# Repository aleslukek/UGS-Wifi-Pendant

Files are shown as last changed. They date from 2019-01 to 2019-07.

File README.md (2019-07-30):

# UGS-Wifi-Pendant
This is an addon for an [Universal Gcode Sender](https://github.com/winder/Universal-G-Code-Sender). It enables a bit more complicated control of your CNC as well as LCD output of useful info.

It supports Old and New pendant. Communication is done via Wifi OR USB Serial. However, if you'd want for communication to work via USB cable (more reliable) you will have to have PowerShell script running in the background. This script listens to Serial on COM port (COMX should be replaced with the COM port of the Pendant device connected to the computer) and converts them to web and get requests via localhost to UGS Pendant. So it is quick, reliable but it is a bodge work. Not elegant but it works. I do not speak java good enough to implement this into UGS. I built this feature upon already working Wifi solution.

## What it does?
It takes buttons input and translates it to web requests that commands UGS via it's wifi pendant. You can move CNC (x, y z), slow move, start home cycle, z probe, reset XYZ zero, reset Z zero, return to XY zero, return to Z zero, pause, start job, cancel, toggle laser mode, soft reset, toggle source computer, auto connect GRBL Arduino to UGS, etc.

When the job is done it can send a notification via IFTTT.com.

OTA updates via local network (tested via Arduino IDE)!

It uses LCD to output CNC data, such as machine position, work position, job duration, job time remaining, job sent rows, total rows, progress, errors and things like that.

When job is running most of the buttons are disabled. Only pause, cancel and toggles are working. So you can't accidentally send commands that have nothing to do with job running.

## What buttons do?

* Button 0 - Homing / Z Probe
* Button 1 - Reset XYZ Zero / Reset Z zero
* Button 2 - Shift, if slow toggle is 1, and laser mode is 1 shift turns on laser test
* Button 3 - Pause-Resume / Laser mode (toggle laser mode if enableLaserMode is enabled) OR toggle Check mode
* Button 4 - Cancel (or $X on idle) / Soft reset + $X
* Button 5 - Y- / Return to XY zero
* Button 6 - Y+ / Return to XY zero
* Button 7 - X- / Return to XY zero
* Button 8 - X+ / Return to XY zero
* Button 9 - Z- / Return to Z zero
* Button 10 - Z+ / Return to Z zero
* Button 11 - Slow/fast toggle for jogging
* Button 12 - N/A
* Button 13 - N/A
* Button 14 - N/A
* Button 15 - PC1, PC2 toggle

--

* Buttons 5 - 10: jogging buttons. They work in two ways: press and hold a button will start jogging. When you release a button it will stop the movement. Second way is a quick press on a button it will start moving until the full step size is reached or until you press cancel or any jog button again.
* Button 2 acts as shift. Example: If you press button 0 CNC starts homing cycle. If you press button 2 (shift) + button 0 then it starts probing.  
* Button 3 start job if file selected when CNC is idle and pauses job when CNC is running.
* Button 2 + Button 3 (shift + pause) toggles laser mode $32=1 and $32=0. This pendant is unaware of current CNC laser mode. So if you press those two buttons even if laser mode is on it will turn it on not off. And vice versa. When laser mode is on led 1 is on.
* Button 4 cancels running job or jog, but acts as $X when idle. Shift + Button 4 soft resets the GRBL device.
Button 11 is as toggle. When not pressed CNC jogs with higher feed rate. When toggle is pressed, led 2 turns on and jogging is slower.
* Button 2 + any X/Y button returns to XY work zero (G90 G0 X0 Y0). This action observes slow/quick toggle and acts accordingly.
* Button 2 + any Z button returns to Z work zero (G90 G0 Z0). This action observes slow/quick toggle and acts accordingly.
* When laser mode is on ($32=1) and slow toggle is also on (so both LEDs are on) button 2 acts as laser test fire. It fires laser at slowest power. Be aware that if you have spindle connected to Spindle enable pin on grbl Arduino it will turn on your spindle. That might be much more dangerous than laser on lowest power. But lasers are dangerous as well, don't get me wrong. USE AT YOUR OWN RISK!

## What it needs?

  * ESP8266
  * At least two shift in registers 74HC165N
  * LM324N Op amp -> this could help with signalling 0V when button not pressed and +V when button pressed
  * I2C LCD 16*2
  * Buttons - momentary 5x
  * Moaar buttons - rocker switch on-off-on 3x
  * Toggle buttons/switches 2x
  * Trimmer 100k or 10k
  * Screw terminal
  * 22uF capacitors 16x
  * 1000k resistors 16x
  * 2 LEDs

* Be mindful that button must be connected in such a way that signals 0V when not pressed and +V (3.3V) when pressed. If you only send +V when button is pressed and not 0V when not pressed it will trigger shift registers.

## IFTTT notification

To enable IFTTT notification you must find your IFTTT Key found [somewhere here](https://ifttt.com/maker_webhooks) and assign it to "iftttKey" variable. Also at this point you must make an event (trigger) with event name. IFTTT event name must match to a variable "iftttEventName" found in UGS_Wifi_Pendant.ino. I would recommend IFTTT notification action to be: "CNC event on {{OccurredAt}}. Message: {{Value1}}". Value1 is an event message.

IFTTT notification happens when job is aborted by an error (hard limit or general error) or when CNC goes to sleep mode after a job - if a gcode file has $SLP at the end.
Canceling and pausing a job wont trigger a notification (since you are probably standing next to it). Also if a job does not have a $SLP at the end of a gcode file this will not send a notification. You should always use $SLP when doing a job when you are not around.

## How to compile...

Obviously you'll need Arduino IDE or something that sends code to your ESP8266.
Then you'll have to set some things up, really simply. You don't need to change any other code other than the one in UGS_Wifi_Pendant.ino

* Pendant version. Uncomment the version you have. If you still use old UGS Wifi Pendant then uncomment OLD_PENDANT. If you use New Pendant and via Wifi use NEW_BREILERS_PENDANT. If you use New Pendant and via USB use BUTTONSTOSERIAL. ONLY ONE SHOULD BE UNCOMMENTED! BUTTONSTOSERIAL only works with new pendant.
        //#define OLD_PENDANT
        //#define NEW_BREILERS_PENDANT
        //#define BUTTONSTOSERIAL

* Wifi settings, self-explanatory. Just enter ssid and wifi password.

* If you have CNC dedicated pc (or Raspberry pi) but also use laptop occasionally to control CNC you can use toggle to switch between them. I highly recommend to set static network ip for those devices on your local router. Name pc 1 and give it local ip. Also for pc 2. Or a mac or anything else that runs UGS. Server port is set to default to 8080 for both devices. I don't see a need for different ports on different devices. So it's the same one for both of them. Port name is so the UGS Pendant can auto-connect GRBL Device to UGS.

        controler1Name "PC1" //PC 1 name
        webserver1 "xxx.xxx.xxx.xxx" //PC 1 local ip
        port1 "COMX" //PC 1 GRBL arduino port name

        controler2Name "PC2" //PC 2 name
        webserver2 "xxx.xxx.xxx.xxx" //PC 2 local ip
        port2 "COMX" //PC 2 GRBL arduino port name

        webserverport = "8080";

        iftttKey - your IFTTT Webhook key
        iftttEventName - ifttt event name. MUST match the one on IFTTT website.

#### Personal settings that make anything working better.
         xyStepSizeFast 800  - x and y step size for quick jog. Might be as long as you want.
         xyStepRateFast 5000 - x and y feed rate for quick jog
         xyStepSizeSlow 200 - x and y step size for slow jog
         xyStepRateSlow 500 - x and y feed rate for slow jog
         probeStep 20 - probing Z axis step size
         probeRate 50 - probing Z axis feed rate
         drillProbeHeight 2 - height of a probe. When it reaches a probe it will offset Z axis for this amount of mm
         enableLaserMode true - if you also use laser keep this enabled. If not it won't use any of those laser features
         laserProbeHeight 0 - probing Z axis probe offset. Same function as drillProbeHeight but different offset if you need
         skipGetDelay 50 - when button is pressed, no other button will register after skipGetDelay milliseconds
         skipMsgDelay 1000 - when button is pressed, display what happened and after skipMsgDelay milliseconds display regular status
         turnBacklightDelay 600000 - turn off LCD backlight after this many milliseconds of inactivity
         jumpSign 5000 - jump sign after 5000 ms (cycling data when idle or running)
         autoResetAlarm false - if you want for pendant to automatically send $X when idle and alarm was triggered (not Hard Limit alarm) set true, else it will not
         autoResetStartupAlarm true - automatically send $X on startup to remove general alarm
         enableSerialOutput true - Enables serial output. For debugging purposes. Disable if not needed. Will make code run a small bit faster.
         enableIftttMessaging true - Enables IFTTT notifications.

         enableOTAUpdate true - enables Over The Air (over local wifi) firmware updates.
         enableOTAPassword true - enables the need for password when OTA updating.
         OTAPassword "******" - if enableOTAUpdate is enabled, enter a password you will have to enter when OTA updating next time. This password is printed on fresh boot via serial.

#### Personal settings for serialToUGS.ps1 file.
        Basically you will only need to figure out what COM port UGS pendant uses. So rename COMX in $PORT='COMX' to whatever COM port it is used. COM5 in my case. If you change USB Port you should change this as well.
        Make sure it works in the background. You can use Windows Task Scheduler to make it start on boot as described [here](https://blog.netwrix.com/2018/07/03/how-to-automate-powershell-scripts-with-task-scheduler/).

* LCD language. Uncomment the wanted one and comment the unwanted one. Currently English and Slovenian. If you'd like to contribute or change, language is in file e_lcd_lang.ino
#define LanguageEnglish
//#define LanguageSlovenian

* Extra, non standard libraries are included in the sketch in src folder. Leave them there, since libraries are pointed there.

* This code checks for buttons state and button logic more than 1000 times per second. When state of any button changes it sends a request. It is done fairly quickly and I haven't encountered any lags or delays. LCD is updated almost every half a second or so. So everything works quite tightly.

# Connections
 * 3V - LCD VCC
 * GND - LCD GND
 * D1 - LCD SCL
 * D2 - LCD SDA
 * D3 - led for laser mode status (on if laser mode is on)
 * D5 - led for speed mode status (on if slow)

Please refer to schematic in schematic folder for if you'd like to make a PCB for it. I made it, trust me, it is worth it. Soldering this is a path you don't want to go to. I used https://easyeda.com to design the schematic (you can easily import it in easyeda. I haven't tested other schematic apps) and pcb and https://jlcpcb.com/ to manufacture 10 pieces for 2 USD + shipping.

# Known issues
* Old UGS Pendant: Soft reset won't work until UGS starts to support soft reset via get request. New UGS Pendant has a soft reset so it works.
* Laser test fire doesn't fire consistently. When it does it might freeze grbl. But sometimes it does not. Not because get requests are not getting through but for some (so far to me) unknown reason, I assume connected to grbl.
* Very rarely jogging stops responding. It start moving and then it doesn't stop. Cancel button doesn't work, it jogs until it hits hard limit switch. For that reason I would strongly recommend to ONLY use this pendant on machines that have hard limits working in all directions. For safety reason of course. I haven't pinpointed the issue to either wifi pendant, ugs, grbl or esp pendant. - On new pendant and USB communication I haven't encountered this issue while testing. USB makes things MUCH MORE reliable so this things should not occur again. Requests via wifi might get delayed or lost in a transmition.

# WARNING
Before embarking on this project READ THIS README! And then again and again. Then think before you do anything that can endanger personal safety or cause damage. Make sure you understand how it works before start using it!

Use this UGS_Wifi_Pendant **ONLY** on machines that have hard limit switches in **ALL** directions! If things start moving and you for some reason don't or can't press stop button at least have limit switches that stop everything.

Read and understand what buttons and combination of buttons do! Failing to understand this might endanger your personal safety and might cause damage to your machine. And other things.

Wear your safety glasses and ear mufflers.

**AND ALWAYS KEEP YOUR HANDS AND OTHER EQUIPMENT OFF YOUR CNC WHEN USING IT!**

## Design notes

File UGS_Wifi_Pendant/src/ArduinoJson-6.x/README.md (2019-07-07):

ArduinoJson

---







ArduinoJson is a C++ JSON library for Arduino and IoT (Internet Of Things).

## Features

* JSON decoding (comments are supported)
* JSON encoding (with optional indentation)
* MessagePack
* Elegant API, easy to use
* Fixed memory allocation (zero malloc)
* No data duplication (zero copy)
* Portable (written in C++98, can be used in any C++ project)
* Self-contained (no external dependency)
* Small footprint
* Input and output streams
* [100% code coverage](https://coveralls.io/github/bblanchon/ArduinoJson)
* [Header-only library](https://en.wikipedia.org/wiki/Header-only)
* [MIT License](https://en.wikipedia.org/wiki/MIT_License)
* [Comprehensive documentation](https://arduinojson.org?utm_source=github&utm_medium=readme)

## Compatibility

ArduinoJson works on the following hardware:

*  Arduino boards: [Uno](https://www.arduino.cc/en/Main/ArduinoBoardUno), [Due](https://www.arduino.cc/en/Main/ArduinoBoardDue), [Mini](https://www.arduino.cc/en/Main/ArduinoBoardMini), [Micro](https://www.arduino.cc/en/Main/ArduinoBoardMicro), [Yun](https://www.arduino.cc/en/Main/ArduinoBoardYun)...
*  Espressif chips: [ESP8266](https://en.wikipedia.org/wiki/ESP8266), [ESP32](https://en.wikipedia.org/wiki/ESP32)
*  WeMos boards: [D1](https://wiki.wemos.cc/products:d1:d1), [D1 mini](https://wiki.wemos.cc/products:d1:d1_mini),  ...
*  RedBearLab boards: [BLE Nano](http://redbearlab.com/blenano/), [BLE Mini](http://redbearlab.com/blemini/), [WiFi Micro](https://redbear.cc/product/wifi/wifi-micro.html), [LOLIN32](https://wiki.wemos.cc/products:lolin32:lolin32)...
*  [Teensy](https://www.pjrc.com/teensy/) boards
*  Intel boards: Edison, Galileo...
*  Particle boards: [Photon](https://www.particle.io/products/hardware/photon-wifi-dev-kit), [Electron](https://www.particle.io/products/hardware/electron-cellular-dev-kit)...
*  Texas Instruments boards: [MSP430](http://www.ti.com/microcontrollers/msp430-ultra-low-power-mcus/overview/overview.html)...

ArduinoJson compiles with zero warning on the following compilers, IDEs, and platforms:

*  [Arduino IDE](https://www.arduino.cc/en/Main/Software)
*  [PlatformIO](http://platformio.org/)
*  [Energia](http://energia.nu/)
*  [Visual Micro](http://www.visualmicro.com/)
*  [Atmel Studio](http://www.atmel.com/microsite/atmel-studio/)
*  [IAR Embedded Workbench](https://www.iar.com/iar-embedded-workbench/)
*  [Atollic TrueSTUDIO](https://atollic.com/truestudio/)
*  [Keil uVision](http://www.keil.com/)
*  [MPLAB X IDE](http://www.microchip.com/mplab/mplab-x-ide)
*  [GCC](https://gcc.gnu.org/)
*  [Clang](https://clang.llvm.org/)
*  [Visual Studio](https://www.visualstudio.com/)

## Quickstart

### Deserialization

Here is a program that parses a JSON document with ArduinoJson.

```c++
char json[] = "{\"sensor\":\"gps\",\"time\":1351824120,\"data\":[48.756080,2.302038]}";

DynamicJsonDocument doc(1024);
deserializeJson(doc, json);

const char* sensor = doc["sensor"];
long time          = doc["time"];
double latitude    = doc["data"][0];
double longitude   = doc["data"][1];
```

See the [tutorial on arduinojson.org](https://arduinojson.org/doc/decoding/?utm_source=github&utm_medium=readme)

### Serialization

Here is a program that generates a JSON document with ArduinoJson:

```c++
DynamicJsonDocument doc(1024);

doc["sensor"] = "gps";
doc["time"]   = 1351824120;

JsonArray data = doc.createNestedArray("data");
data.add(48.756080);
data.add(2.302038);

serializeJson(doc, Serial);
// This prints:
// {"sensor":"gps","time":1351824120,"data":[48.756080,2.302038]}
```

See the [tutorial on arduinojson.org](https://arduinojson.org/doc/encoding/?utm_source=github&utm_medium=readme)

## Documentation

The documentation is available on [arduinojson.org](https://arduinojson.org/?utm_source=github&utm_medium=readme), here are some shortcuts:

* The [Examples](https://arduinojson.org/example/?utm_source=github&utm_medium=readme) show how to use the library in various situations.
* The [API Reference](https://arduinojson.org/api/?utm_source=github&utm_medium=readme) contains the description of each class and function.
* The [FAQ](https://arduinojson.org/faq/?utm_source=github&utm_medium=readme) has the answer to virtually every question.
* The [ArduinoJson Assistant](https://arduinojson.org/assistant/?utm_source=github&utm_medium=readme) writes programs for you!

---

Do you like this library? Please [star this project on GitHub](https://github.com/bblanchon/ArduinoJson/stargazers)!

What? You don't like it but you *love* it?
We don't take donations anymore, but [we sell a book](https://arduinojson.org/book/?utm_source=github&utm_medium=readme), so you can help and learn at the same time!

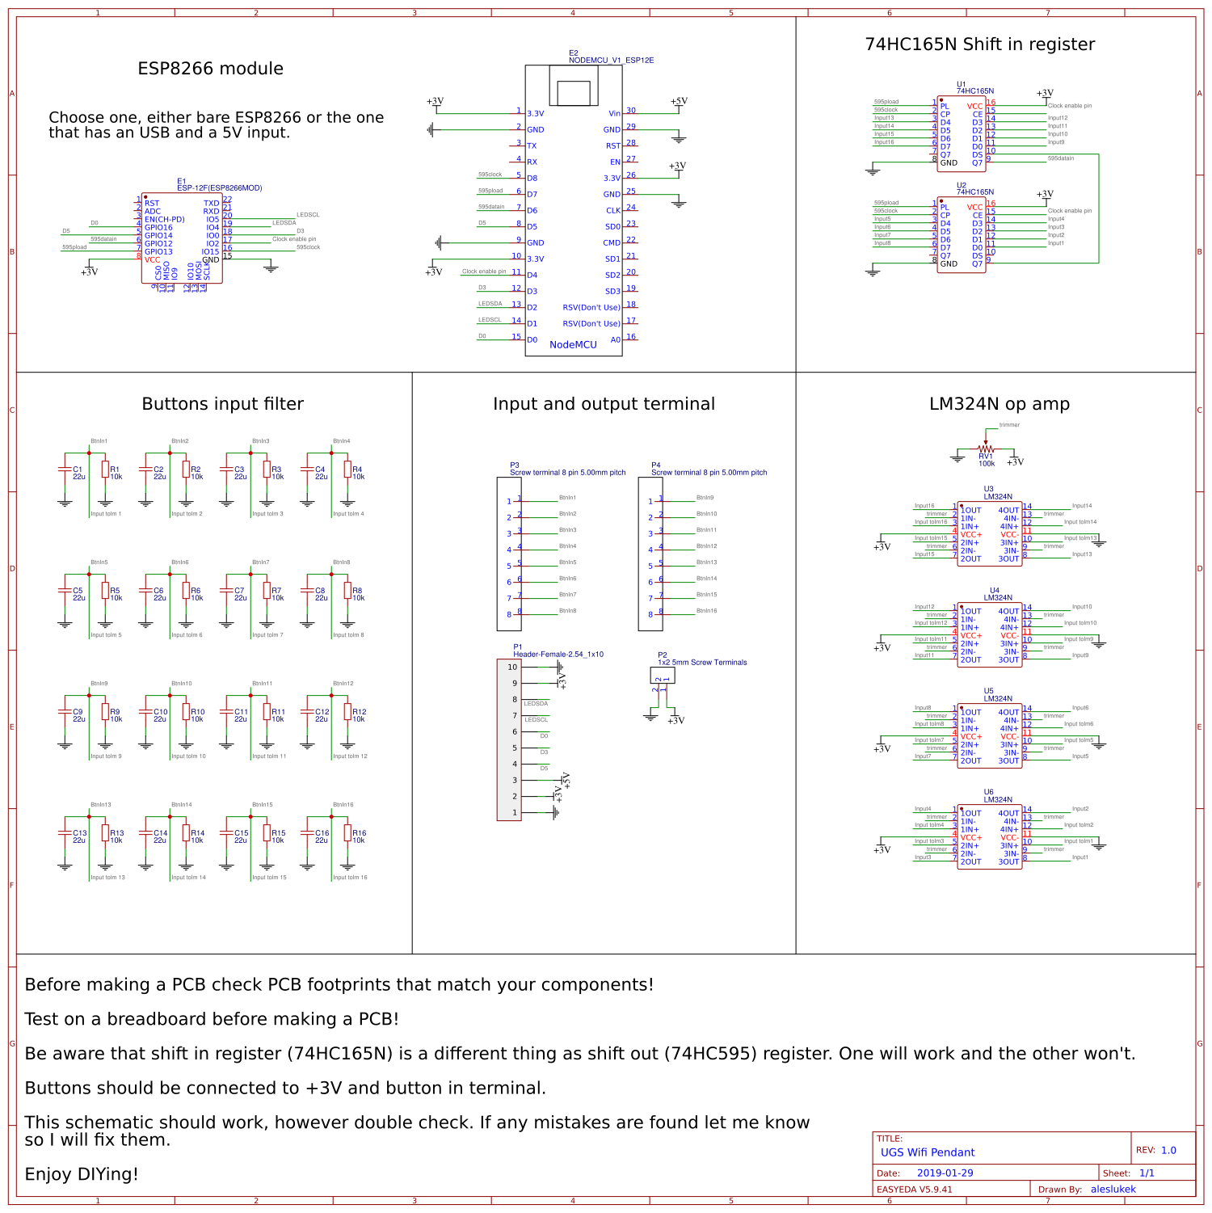
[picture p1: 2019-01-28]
Schematic/ugs wifi pendant.png

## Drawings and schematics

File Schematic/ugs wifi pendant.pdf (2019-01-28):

+3V | +5V

+3V

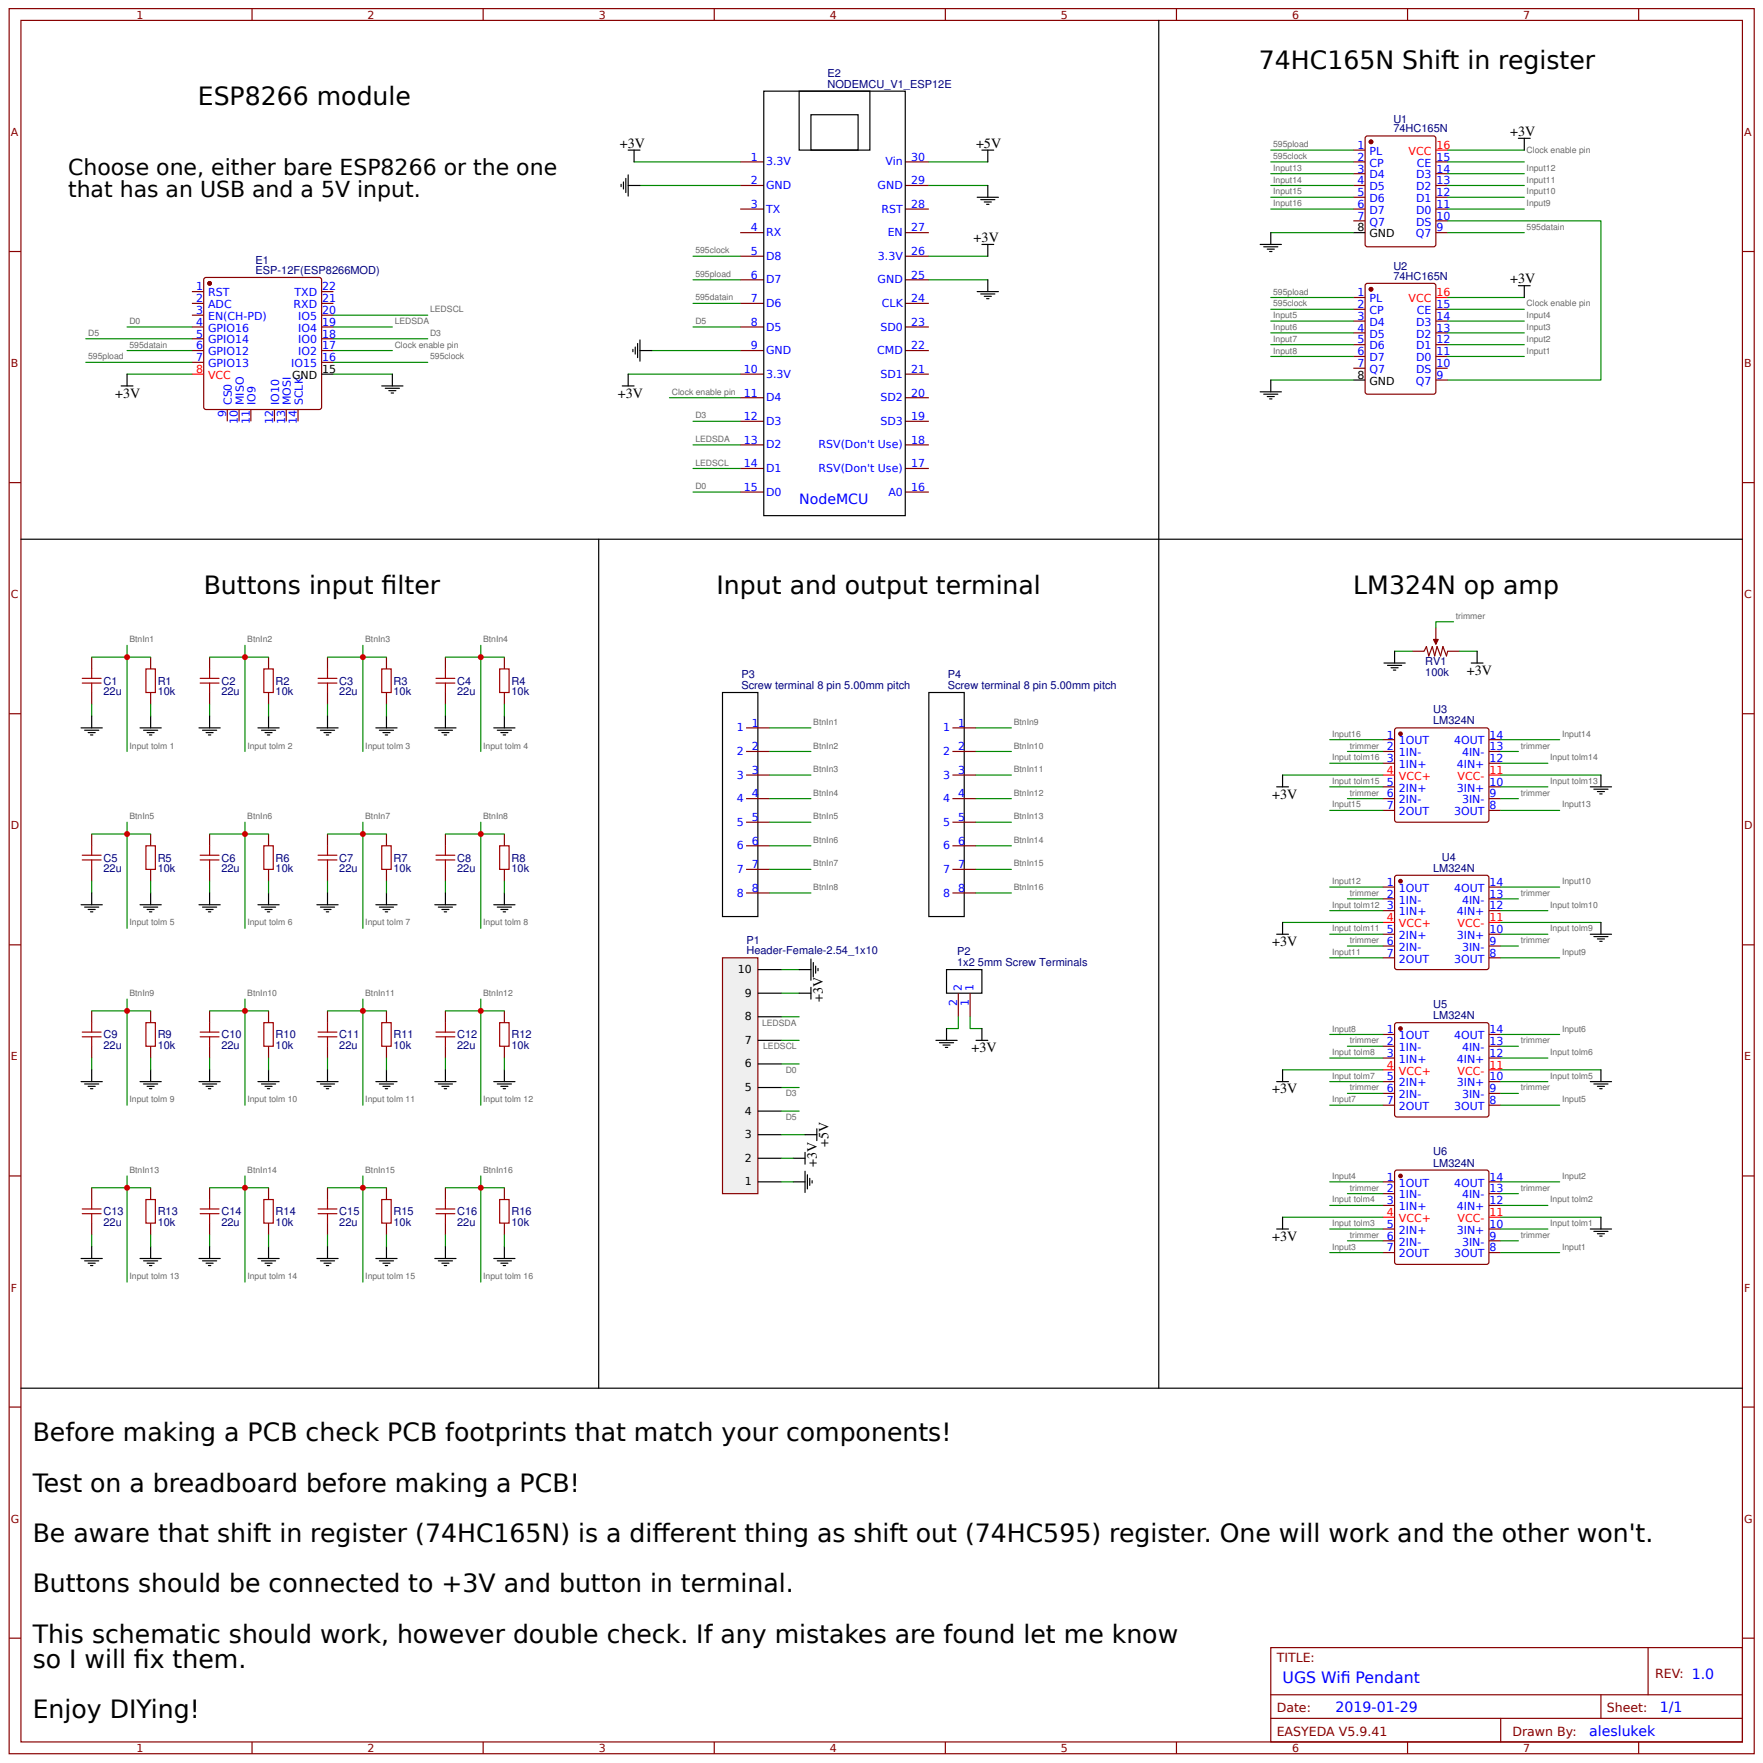
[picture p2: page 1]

Choose one, either bare ESP8266 or the one
that has an USB and a 5V input.

Screw terminal 8 pin 5.00mm pitch

Before making a PCB check PCB footprints that match your components!
Test on a breadboard before making a PCB!
Be aware that shift in register (74HC165N) is a different thing as shift out (74HC595) register. One will work and the other won't.
Buttons should be connected to +3V and button in terminal.
This schematic should work, however double check. If any mistakes are found let me know
so I will fix them.
Enjoy DIYing!

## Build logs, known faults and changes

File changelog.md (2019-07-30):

# 1.21 - 31.7.2019
* Small bug fixes.
* Removed chosen file name on LCD.
* Showing progress % was accidentally removed in previous build. Now it works.

# 1.20 - 8.7.2019
* This is a big one, guys! Added support for New Mr. Breiler's Pendant via Wifi.
* Also! Added support for New Pendant, BUT VIA USB! So This Wifi Pendant takes data via wifi, still has IFTTT messaging but commands are sent via USB cable. Since ESP cannot act as keyboard I managed a bodge - Powershell script (serialToUGS.ps1) that runs in a back that listens Wifi Pendant COM port and converts Serial Commands to localhost web requests. So Wifi Pendant should still run in a background. Since this are localhost requests commands are quicker, more reliable even if Pendant doesn't have the best wifi signal.
* Old pendant is as is, now Json Parsing is done by ArduinoJson 6 library. Better than my previous parser.
* Soft reset now works on new pendant.
* Some small bugs removed.
* Via this new pendant it is now possible that Wifi pendant automatically connects UGS to CNC. And cancels first Alarm.
* I couldn't be bothered but I assume that by using powershell you could remove the need for wifi (ESP) - so almost any Arduino could be used. I won't check since I have other things to do.

# 1.05 - 24.2.2019
* Added OTA updates. You can now update your module wirelessly. You can enable or disable OTA updates. You can also enable or disable OTA password.
* Changed how progress is being calculated. So it better handles empty rows and comments in gcode file.
* Changed how estimated remaining time is being calculated; it should not jump around like in UGS does. And it is more accurate. And it works by applying magic.

# 1.04 - 16.2.2019
* Added a notification system; it sends notifications to your phone via IFTTT.com when job is finished/aborted.
* Introduced small delay (20ms) to cancel command in cases when cancel command is requested right after jog command. This cancel command overrules 50 ms delay to all get requests.
* Some readme updates.
* Fixed speed issue when "return to zero" was not observing rate toggle (button 11).

# 1.03 - 13.2.2019
* Bugfix, added G91 to z probe. Sometimes Z probe was probing in wrong direction, depending on Z zero.

# 1.02 - 13.2.2019
* Some small code cleanup.

# 1.01 - 3.2.2019
* Added "return to zero" function. It splits XY return to zero and Z return to zero. Shift + direction buttons. Shift + X or Shift + Y to return to XY zero and Shift + Z to return to Z zero. It observes slow/quick toggle switch position for quick or slow return.

# 1.0
* Initial release.

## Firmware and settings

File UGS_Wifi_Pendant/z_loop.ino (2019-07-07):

//=======================================================================
//                    Main Program Loop
//=======================================================================
void loop() {
        read_shift_regs(); //read button state always, even if not connected
        buttonValues = read_shift_regs();
        //Serial.println(buttonValues);
        if(oldButtonValues != buttonValues) { //if any button was pressed, do your magic
                buttons();
                directionButtons();
                oldButtonValues = buttonValues;
                timer2 = millis(); //if any button was pressed reset backlight timer
                if(lcdBacklightStatus == 0) { //turn backlight on if it was turned off
                        lcd.backlight();
                        lcdBacklightStatus = 1;
                }
        }

        if((cnc_state[4] == 1 || cnc_state[7] == 1) && (directionStatus == 1 || directionStatusX == 1 || directionStatusY == 1 || directionStatusZ == 1) && (button[5] == 0 && button[6] == 0 && button[7] == 0 && button[8] == 0 && button[9] == 0 && button[10] == 0) ) { //re-check if button was de-pressed to stop the movement: when idle or jogging, buttons are not pressed, it should be moving
                directionStatusX = 0;
                directionStatusY = 0;
                directionStatusZ = 0;
                getCommandGeneral(GETcancel);
        }

        maintanance();
        if(cycleCounter % 1000 == 0) { //read UGS GET output every 1000 cycles
                timer4 = millis();
                //printSerialDebug(0);
                readUGSPendant();
                //printSerialDebug(1);
                if(cnc_state[0] == 1) { //if not connected to wifi, retry to connect
                        reConnectToWifi();
                }
                //printSerialDebug(3); //to time 1000 cycles and one get response read and parse
        }
        //printSerialDebug(3); //to time average of 100 cycles
}

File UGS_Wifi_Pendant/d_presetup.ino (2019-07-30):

#include <ESP8266WiFi.h>
#include <WiFiClient.h>
#include <ESP8266WebServer.h>
#include <ESP8266HTTPClient.h>
#include "src/ESP8266Ping/ESP8266Ping.h"
#include <ESP8266mDNS.h>
#include <WiFiUdp.h>
#include <ArduinoOTA.h>
#include "src/LiquidCrystal_I2C/LiquidCrystal_I2C.h"
#include "src/ArduinoJson-6.x/ArduinoJson.h"

#define  pendatVersion  1.21

LiquidCrystal_I2C lcd(0x3F, 16, 2);
#define resetPinD5 16 //D0

#define ledLaser 0 //D3 - led for laser mode status (on if lasermode is on)
#define ledSlow  14//D5 - led for speed mode status (on if slow)

bool justSentGeneral = 0;
bool justSentDirection = 0;
bool justSentMsgDisplay = 0;
bool ledLaserStatus = 0;
bool ledSlowStatus = 0;
int buttonPressMsg = 0; //what message to display when certain button is pressed
unsigned long timer1 = 0; //reset justSentGeneral to 0 after skipGetDelay ms
unsigned long timer2 = 0; //turn off backlight after turnBacklightDelay ms
unsigned long timer3 = 0; //calculate cycle duration
unsigned long timer4 = 0; //calculate cycle ugs get and parse duration
unsigned long timer5 = 0; //reset msg display after skipMsgDelay ms
unsigned int cycleCounter = 1;
unsigned int timerlcd = 0;
bool disableAlarmLockLogic = 1; //will send $X on startup if enabled. Also there to automatically send $X if alarm is set. Not for Hard Limit alarm
bool resetZAxisAfterProbe = 0;
bool turnOnLCD = 0;
bool lcdBacklightStatus = 0;
byte showLCD = 0;
bool laserMode = 0;
bool laserTest = 0;
bool connectCNCOnce = 0; //if 0 it connects CNC to computer automagically, if not then it will not connect CNC to computer
#define numOfStates 15
bool cnc_state[numOfStates] = {0, 0, 0, 0, 0, 0, 0, 0, 0, 0, 0, 0, 0, 0, 0};


/*

   CNC_State index:
   0 - esp wifi not connected
   1 - PC not available
   2 - PC available ugs or pendant not running
   3 - PC available, ugs available, arduino (cnc) connected to PC via serial
   4 - CNC is idle
   5 - CNC job is running
   6 - CNC job is on hold
   7 - CNC is jogging
   8 - Hard Limit Alarm triggered
   9 - General Alarm triggered
   10 - CNC is sleeping ($SLP triggered)
   11 - send btn enabled
   12 - pause btn enabled
   13 - cancel btn enabled
   14 - disable certain buttons while job is being done
 */

#define varLength 17
char textArray[500];
char variable[18][varLength];
String variableNames[17];

float workx, worky, workz, machinex, machiney, machinez;
float rowProgress;
int rowsInFile, sentRows, remainingRows, timeRemaining, duration;

bool button[16] = {0, 0, 0, 0, 0, 0, 0, 0, 0, 0, 0, 0, 0, 0, 0, 0};
bool prevButton[16] = {0, 0, 0, 0, 0, 0, 0, 0, 0, 0, 0, 0, 0, 0, 0, 0};
unsigned int buttonValues;
unsigned int oldButtonValues;

/*
   button[0] - top left button, Homing / Probe
   button[1] - top right button, Reset XYZ / Reset Z zero
   button[2] - middle button, Shift, if slow toggle is 1, and laser mode is 1 shift turns on laser test
   button[3] - bottom left button, Pause-Resume / Laser mode (toggle laser mode)
   button[4] - bottom right button, Cancel (or $X on idle) / Soft reset + $X
   button[5] - Y- / return to XY zero
   button[6] - Y+ / return to XY zero
   button[7] - X- / return to XY zero
   button[8] - X+ / return to XY zero
   button[9] - Z- / return to Z zero
   button[10] - Z+ / return to Z zero
   button[11] - slow/fast toggle for jogging
   button[12] - N/A
   button[13] - N/A
   button[14] - N/A
   button[15] - PC 1, PC 2 toggle
 */

// How many shift register chips are daisy-chained.
#define NUMBER_OF_SHIFT_CHIPS   2

// Width of data (how many ext lines).
#define DATA_WIDTH   NUMBER_OF_SHIFT_CHIPS * 8

// Width of pulse to trigger the shift register to read and latch.
#define PULSE_WIDTH_USEC   5

#define ploadPin        13 // Connects to Parallel load pin the 165
#define clockEnablePin  2 // Connects to Clock Enable pin the 165
#define dataPin         12 // Connects to the Q7 pin the 165
#define clockPin        15 // Connects to the Clock pin the 165

#ifdef OLD_PENDANT //old pendant commands
#define   GETmovexyz                "/sendGcode/?gCode=%24J%3DG21G91"
#define   GETresetzero              "/sendGcode/?gCode=G10%20P0%20L20%20X0%20Y0%20Z0"
#define   GETresetZzero             "/sendGcode/?gCode=G10%20P0%20L20%20Z"
#define   GETreturntozero           "/sendGcode/?gCode=RETURN_TO_ZERO"
#define   GETmoveToZeroZslowly      "/sendGcode/?gCode=G1%20G90%20Z0%20F50" //return to Z0 slowly
#define   GETmoveToZeroZquickly     "/sendGcode/?gCode=G1%20G90%20Z0%20F500" //return to X0 quickly
#define   GETmoveToZeroXYslowly     "/sendGcode/?gCode=G1%20G90%20X0%20Y0%20F500" //return to XY slowly
#define   GETmoveToZeroXYquickly    "/sendGcode/?gCode=G1%20G90%20X0%20Y0%20F5000" //return to XY quickly
#define   GETreturntoworkspace      "/sendGcode/?gCode=G0%20G90%20X0%20Y0%20Z0"
#define   GEThomingcycle            "/sendGcode/?gCode=%24H"
#define   GETdisablealarmlock       "/sendGcode/?gCode=%24X"
#define   GETtogglecheckmode        "/sendGcode/?gCode=%24C"
#define   GETsoftreset              "/sendGcode/?gCode=%24C" //run toggle check mode twice in a row
#define   GETspindleON              "/sendGcode/?gCode=M8"
#define   GETspindleOFF             "/sendGcode/?gCode=M9"
#define   GETpause                  "/sendGcode/?gCode=PAUSE_RESUME_FILE"
#define   GETsend                   "/sendGcode/?gCode=SEND_FILE"
#define   GETresume                 "/sendGcode/?gCode=PAUSE_RESUME_FILE"
#define   GETcancelJob              "/sendGcode/?gCode=CANCEL_FILE"
#define   GETcancel                 "/sendGcode/?gCode=CANCEL_FILE"
#define   GETsystemState            "/getSystemState/"
#define   GETtoggleLaser            "/sendGcode/?gCode=%2432%3D" //%36 should be $ Laser toggle is $32=
#define   GETlaserTestOn            "/sendGcode/?gCode=M3" //Run test as M04 Sxx (xx are laserTestStrength) - this will only turn on laser, but not fire it yet, since G1 command is not issued
#define   GETlaserTestPower         "/sendGcode/?gCode=M4%20S1" //Run test as M04 Sxx (xx are laserTestStrength) - this will only turn on laser, but not fire it yet, since G1 command is not issued
#define   GETlaserTestOff           "/sendGcode/?gCode=M5" //Turn off M4 with M05
#define   GETmoveLeftABit           "/sendGcode/?gCode=G1%20G91%20X-0.1%20F5000" //move relative 0.1 mm to left
#define   GETmoveRightABit          "/sendGcode/?gCode=G1%20G91%20X0.1%20F5000" //move relative 0.1 mm to right
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

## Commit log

2019-02-16 1.04
    IFTTT notifications, bug fixes
    [UGS_Wifi_Pendant.ino, d_presetup.ino, e_lcd_lang.ino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]
2019-02-24 1.05 update
    OTA, progress calculation fixed, time remaining calculation fixed
    [UGS_Wifi_Pendant.ino, d_presetup.ino, e_lcd_lang.ino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]
